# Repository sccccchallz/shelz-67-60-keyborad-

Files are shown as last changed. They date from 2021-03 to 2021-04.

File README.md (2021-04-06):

# shelz-67-60-keyborad-
This is a 67-key keyboard by shelz
(Still working on it)

The basic purpose is to reduce the way that the finger could access the backspace easier but keep the keycaps options same as the normal 64 keyboard.

My keyboard has a closer 1.25U backspace which is near to the key P , one function key (fn2) is set on the left of the backspace key that has not input without other keys together  or lock to another layout such as coleman layout by press the function 1 key together. Therefore, the place of original 2U backspace became "[" and "]".
(you could defintely switch to the defualt 64 layout with double 1U backspace and 1U'[', 1.25'U'] and the 1.25U'\')

Well, I am a brake spacebar lover lol.
And due to my IME useed to typing chinese does not require the numbers to choose characters, I was trying to design the 40%, however, my mommy and daddy are still using the traditional IME，I switched to 60%, If you are from the English speaking contry, you could just delete the first row and switch tab to esc, the tab could use the fn2 to type in, this is why I put the fn2 to the left of the backspace, one is to reduce the typo on the backspace, one is for the easier access to the function key.



Here is my special layout.

the json file for the lceda is in the folder. If you are from China and using the lceda(立创)　you could use dah.

Thanks the KLE and KFB for helping me design my own layout more easily.

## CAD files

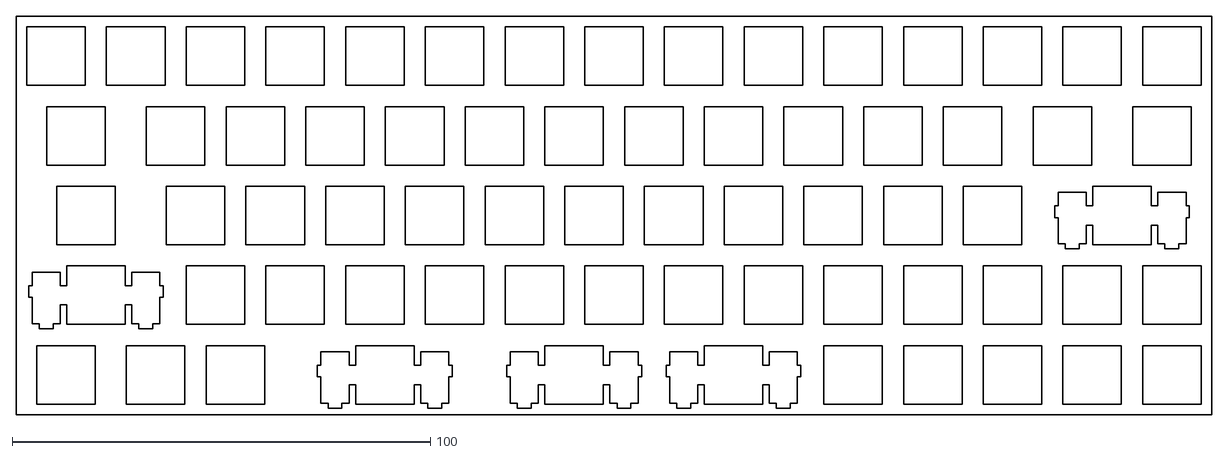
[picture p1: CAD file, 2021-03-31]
0c84b1813b626dbe2195cd7d2c85d890b776f436_switch.dxf
285.7 x 95.2

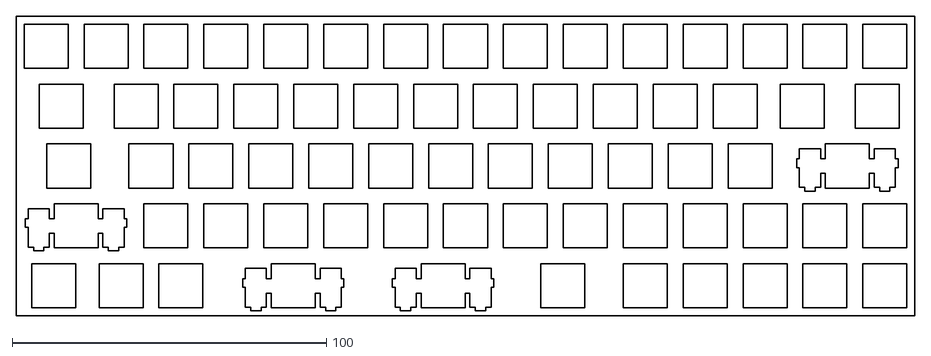
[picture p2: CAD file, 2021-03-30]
ed214658904ac09d7a0528e15d09ae2a5fe1e998_switch.dxf
285.7 x 95.2

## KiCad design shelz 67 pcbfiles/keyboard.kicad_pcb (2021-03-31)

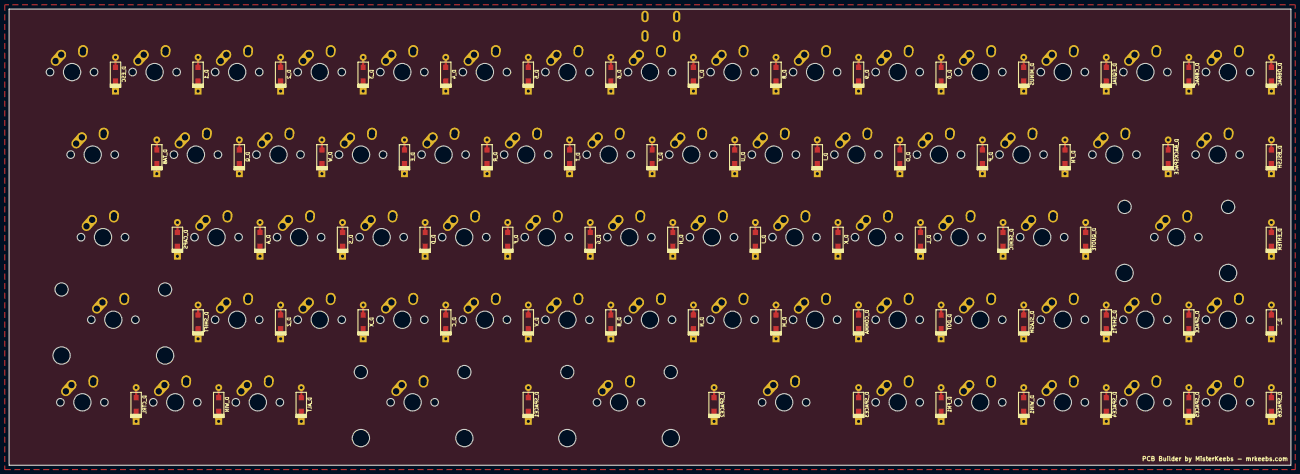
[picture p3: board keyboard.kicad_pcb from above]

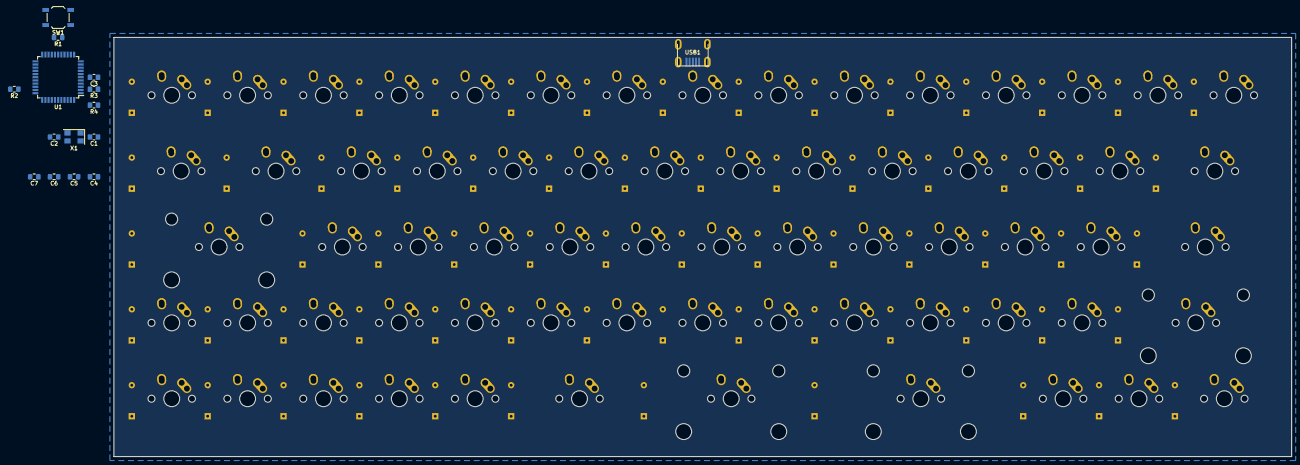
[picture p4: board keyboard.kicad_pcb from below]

Board: 2 copper layers, 295.8 x 105.2 mm, 149 parts (15 on the bottom side), 98 nets, no tracks yet.

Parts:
C1, C2, C3, C4, C5, C6, C7: 22pF; C_0805_2012Metric_Pad1.15x1.40mm_HandSolder
D_0, D_1, D_2, D_3, D_4, D_5, D_6, D_7, D_8, D_9: D; D_SOD123_axial
D_A: D; D_SOD123_axial
D_ALT: D; D_SOD123_axial
D_B: D; D_SOD123_axial
D_BACKSPACE: D; D_SOD123_axial
D_BSLSH: D; D_SOD123_axial
D_C: D; D_SOD123_axial
D_CAPS: D; D_SOD123_axial
D_CBRAC: D; D_SOD123_axial
D_COMMA: D; D_SOD123_axial
D_CTRL: D; D_SOD123_axial
D_D: D; D_SOD123_axial
D_DOT: D; D_SOD123_axial
D_E: D; D_SOD123_axial
D_ENTER: D; D_SOD123_axial
D_EQUAL: D; D_SOD123_axial
D_ESC: D; D_SOD123_axial
D_F: D; D_SOD123_axial
D_FN, D_FN1: D; D_SOD123_axial
D_G: D; D_SOD123_axial
D_H: D; D_SOD123_axial
D_I: D; D_SOD123_axial
D_J: D; D_SOD123_axial
D_K: D; D_SOD123_axial
D_L: D; D_SOD123_axial
D_M: D; D_SOD123_axial
D_MINUS: D; D_SOD123_axial
D_N: D; D_SOD123_axial
D_O: D; D_SOD123_axial
D_OBRAC: D; D_SOD123_axial
D_P: D; D_SOD123_axial
D_Q: D; D_SOD123_axial
D_QUOTE: D; D_SOD123_axial
D_R: D; D_SOD123_axial
D_S: D; D_SOD123_axial
D_SEMIC: D; D_SOD123_axial
D_SHIFT, D_SHIFT1: D; D_SOD123_axial
D_SLASH: D; D_SOD123_axial
D_SPACE, D_SPACE1, D_SPACE2, D_SPACE3, D_SPACE4, D_SPACE5, D_SPACE6: D; D_SOD123_axial
D_T: D; D_SOD123_axial
D_TAB: D; D_SOD123_axial
D_U: D; D_SOD123_axial
D_V: D; D_SOD123_axial
D_W: D; D_SOD123_axial
D_WIN, D_WIN1: D; D_SOD123_axial
D_X: D; D_SOD123_axial
D_Y: D; D_SOD123_axial
D_Z: D; D_SOD123_axial
D_`: D; D_SOD123_axial
K_0, K_1, K_2, K_3, K_4, K_5, K_6, K_7, K_8, K_9: KEYSW; MX-1U-NoLED
K_A: KEYSW; MX-1U-NoLED
K_ALT: KEYSW; MX-1U-NoLED
K_B: KEYSW; MX-1U-NoLED
K_BACKSPACE: KEYSW; MX-1.25U-NoLED
K_BSLSH: KEYSW; MX-1.25U-NoLED
K_C: KEYSW; MX-1U-NoLED
K_CAPS: KEYSW; MX-1.75U-NoLED
K_CBRAC: KEYSW; MX-1U-NoLED
K_COMMA: KEYSW; MX-1U-NoLED
K_CTRL: KEYSW; MX-1.25U-NoLED
K_D: KEYSW; MX-1U-NoLED
K_DOT: KEYSW; MX-1U-NoLED
K_E: KEYSW; MX-1U-NoLED
K_ENTER: KEYSW; MX-2.25U-NoLED
K_EQUAL: KEYSW; MX-1U-NoLED
K_ESC: KEYSW; MX-1U-NoLED
K_F: KEYSW; MX-1U-NoLED
K_FN, K_FN1: KEYSW; MX-1U-NoLED
K_G: KEYSW; MX-1U-NoLED
K_H: KEYSW; MX-1U-NoLED
K_I: KEYSW; MX-1U-NoLED
K_J: KEYSW; MX-1U-NoLED
K_K: KEYSW; MX-1U-NoLED
K_L: KEYSW; MX-1U-NoLED
K_M: KEYSW; MX-1U-NoLED
K_MINUS: KEYSW; MX-1U-NoLED
K_N: KEYSW; MX-1U-NoLED
K_O: KEYSW; MX-1U-NoLED
K_OBRAC: KEYSW; MX-1U-NoLED
K_P: KEYSW; MX-1U-NoLED
K_Q: KEYSW; MX-1U-NoLED
K_QUOTE: KEYSW; MX-1U-NoLED
K_R: KEYSW; MX-1U-NoLED
K_S: KEYSW; MX-1U-NoLED
K_SEMIC: KEYSW; MX-1U-NoLED
K_SHIFT: KEYSW; MX-2U-NoLED
K_SHIFT1: KEYSW; MX-1U-NoLED
K_SLASH: KEYSW; MX-1U-NoLED
K_SPACE, K_SPACE4, K_SPACE5, K_SPACE6: KEYSW; MX-1U-NoLED
K_SPACE1: KEYSW; MX-2.75U-NoLED
K_SPACE2: KEYSW; MX-2.25U-NoLED
K_SPACE3: KEYSW; MX-1.75U-NoLED
K_T: KEYSW; MX-1U-NoLED
K_TAB: KEYSW; MX-1.5U-NoLED
K_U: KEYSW; MX-1U-NoLED
K_V: KEYSW; MX-1U-NoLED
K_W: KEYSW; MX-1U-NoLED
K_WIN, K_WIN1: KEYSW; MX-1U-NoLED
K_X: KEYSW; MX-1U-NoLED
K_Y: KEYSW; MX-1U-NoLED
K_Z: KEYSW; MX-1U-NoLED
K_`: KEYSW; MX-1U-NoLED
R1, R2: 10k; R_0805_2012Metric_Pad1.15x1.40mm_HandSolder
R3, R4: 22; R_0805_2012Metric_Pad1.15x1.40mm_HandSolder
SW1: SW_PUSH; SW_SPST_TL3342
U1: ATMEGA32U4; TQFP-44_10x10mm_P0.8mm
USB1: Molex-0548190589; Molex-0548190589-Assembly
X1: XTAL_GND; Crystal_SMD_5032-4Pin_5.0x3.2mm

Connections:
/col0: K_CAPS.1, K_CTRL.1, K_ESC.1, K_SHIFT.1, K_TAB.1, U1.29
/col1: K_1.1, K_A.1, K_Q.1, K_WIN.1, K_Z.1, U1.30
/col2: K_2.1, K_ALT.1, K_S.1, K_W.1, K_X.1, U1.12
/col3: K_3.1, K_C.1, K_D.1, K_E.1, K_SPACE1.1, U1.31
/col4: K_4.1, K_F.1, K_R.1, K_V.1, U1.32
/col5: K_5.1, K_B.1, K_G.1, K_SPACE2.1, K_T.1, U1.18
/col6: K_6.1, K_H.1, K_N.1, K_Y.1, U1.19
/col7: K_7.1, K_J.1, K_M.1, K_SPACE3.1, K_U.1, U1.20
/col8: K_8.1, K_COMMA.1, K_I.1, K_K.1, U1.21
/col9: K_9.1, K_DOT.1, K_FN1.1, K_L.1, K_O.1, U1.25
/col10: K_0.1, K_P.1, K_SEMIC.1, K_SLASH.1, K_WIN1.1, U1.22
/col11: K_FN.1, K_MINUS.1, K_QUOTE.1, K_SHIFT1.1, K_SPACE4.1, U1.26
/col12: K_BACKSPACE.1, K_ENTER.1, K_EQUAL.1, K_SPACE.1, K_SPACE5.1, U1.27
/col13: K_BSLSH.1, K_CBRAC.1, K_SPACE6.1, K_`.1, U1.41
/col14: K_OBRAC.1, U1.40
/row0: D_0.1, D_1.1, D_2.1, D_3.1, D_4.1, D_5.1, D_6.1, D_7.1, D_8.1, D_9.1, D_CBRAC.1, D_EQUAL.1, D_ESC.1, D_MINUS.1, D_OBRAC.1, U1.8
/row1: D_BACKSPACE.1, D_BSLSH.1, D_E.1, D_FN.1, D_I.1, D_O.1, D_P.1, D_Q.1, D_R.1, D_T.1, D_TAB.1, D_U.1, D_W.1, D_Y.1, U1.9
/row2: D_A.1, D_CAPS.1, D_D.1, D_ENTER.1, D_F.1, D_G.1, D_H.1, D_J.1, D_K.1, D_L.1, D_QUOTE.1, D_S.1, D_SEMIC.1, U1.10
/row3: D_B.1, D_C.1, D_COMMA.1, D_DOT.1, D_M.1, D_N.1, D_SHIFT.1, D_SHIFT1.1, D_SLASH.1, D_SPACE.1, D_V.1, D_X.1, D_Z.1, D_`.1, U1.11
/row4: D_ALT.1, D_CTRL.1, D_FN1.1, D_SPACE1.1, D_SPACE2.1, D_SPACE3.1, D_SPACE4.1, D_SPACE5.1, D_SPACE6.1, D_WIN.1, D_WIN1.1, U1.28
GND: C1.2, C2.2, C3.2, C4.2, C5.2, C6.2, C7.2, R2.2, SW1.1, U1.5, U1.15, U1.23, USB1.1, X1.2, X1.4
unnamed: C1.1, U1.16, X1.1
unnamed: C2.1, U1.17, X1.3
unnamed: C3.1, U1.6
unnamed: D_0.2, K_0.2
unnamed: D_1.2, K_1.2
unnamed: D_2.2, K_2.2
unnamed: D_3.2, K_3.2
unnamed: D_4.2, K_4.2
unnamed: D_5.2, K_5.2
unnamed: D_6.2, K_6.2
unnamed: D_7.2, K_7.2
unnamed: D_8.2, K_8.2
unnamed: D_9.2, K_9.2
unnamed: D_A.2, K_A.2
unnamed: D_ALT.2, K_ALT.2
unnamed: D_B.2, K_B.2
unnamed: D_BACKSPACE.2, K_BACKSPACE.2
unnamed: D_BSLSH.2, K_BSLSH.2
unnamed: D_C.2, K_C.2
unnamed: D_CAPS.2, K_CAPS.2
unnamed: D_CBRAC.2, K_CBRAC.2
unnamed: D_COMMA.2, K_COMMA.2
unnamed: D_CTRL.2, K_CTRL.2
unnamed: D_D.2, K_D.2
unnamed: D_DOT.2, K_DOT.2
unnamed: D_E.2, K_E.2
unnamed: D_ENTER.2, K_ENTER.2
unnamed: D_EQUAL.2, K_EQUAL.2
unnamed: D_ESC.2, K_ESC.2
unnamed: D_F.2, K_F.2
unnamed: D_FN1.2, K_FN1.2
unnamed: D_FN.2, K_FN.2
unnamed: D_G.2, K_G.2
unnamed: D_H.2, K_H.2
unnamed: D_I.2, K_I.2
unnamed: D_J.2, K_J.2
unnamed: D_K.2, K_K.2
unnamed: D_L.2, K_L.2
unnamed: D_M.2, K_M.2
unnamed: D_MINUS.2, K_MINUS.2
unnamed: D_N.2, K_N.2
unnamed: D_O.2, K_O.2
unnamed: D_OBRAC.2, K_OBRAC.2
unnamed: D_P.2, K_P.2
unnamed: D_Q.2, K_Q.2
unnamed: D_QUOTE.2, K_QUOTE.2
unnamed: D_R.2, K_R.2
unnamed: D_S.2, K_S.2
unnamed: D_SEMIC.2, K_SEMIC.2
unnamed: D_SHIFT1.2, K_SHIFT1.2
unnamed: D_SHIFT.2, K_SHIFT.2
unnamed: D_SLASH.2, K_SLASH.2
unnamed: D_SPACE1.2, K_SPACE1.2
unnamed: D_SPACE2.2, K_SPACE2.2
unnamed: D_SPACE3.2, K_SPACE3.2
unnamed: D_SPACE4.2, K_SPACE4.2
unnamed: D_SPACE5.2, K_SPACE5.2
unnamed: D_SPACE6.2, K_SPACE6.2
unnamed: D_SPACE.2, K_SPACE.2
unnamed: D_T.2, K_T.2
unnamed: D_TAB.2, K_TAB.2
unnamed: D_U.2, K_U.2
unnamed: D_V.2, K_V.2
unnamed: D_W.2, K_W.2
unnamed: D_WIN1.2, K_WIN1.2
unnamed: D_WIN.2, K_WIN.2
unnamed: D_X.2, K_X.2
unnamed: D_Y.2, K_Y.2
unnamed: D_Z.2, K_Z.2
unnamed: D_`.2, K_`.2
unnamed: R1.1, SW1.2, U1.13
unnamed: R2.1, U1.33
unnamed: R3.1, U1.3
unnamed: R4.1, U1.4
unnamed: R3.2, USB1.2
unnamed: R4.2, USB1.3
VCC: C4.1, C5.1, C6.1, C7.1, R1.2, U1.2, U1.14, U1.24, USB1.5
